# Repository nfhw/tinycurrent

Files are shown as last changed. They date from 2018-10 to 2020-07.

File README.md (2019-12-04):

# tinyCurrent – an enhanced uCurrent Gold Derivative

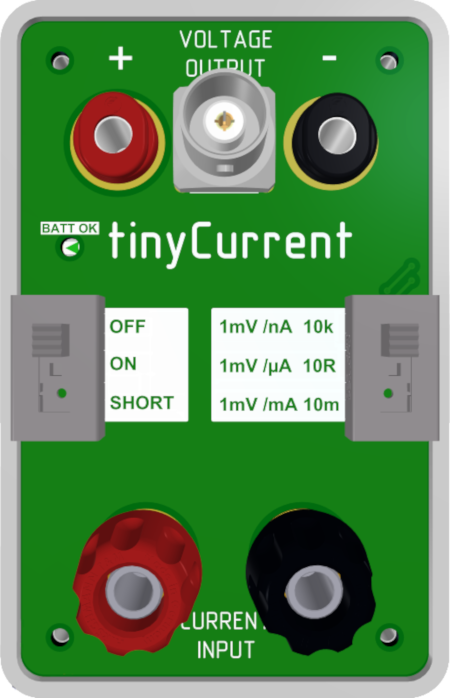
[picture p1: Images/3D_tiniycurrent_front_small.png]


A low cost yet professional low current measurement shunt and amplifier
combination to overcome the issue of high burden voltage as seen with
multimeters and to enable low current measurement by using voltage measurement
devices such as oscilloscopes.

Originally designed and sold by
[Dave Jones on the EEVBLOG](https://www.eevblog.com/projects/ucurrent/),
this derivative has several enhancements specifically for measuring varying
currents on today's low power devices.
Switch mode voltage regulators and the varying current draw of MCUs and RF
chips require the determination of the current draw over time to calculate the
total power consumption of a device. A storage oscilloscope is a perfect tool
for this task and widely available.
That's why the tinyCurrent features a **BNC connector to reduce the picked-up
noise** while measuring with an and oscilloscope. Another problem is the high
dynamics in power draw caused by the aforementioned reasons.
This is addressed by the possibility to
**power the device from an external source**
with up to 5.5 V and bridge R7 using J6 to use the whole positive VDD
as maximum positive output voltage. Both measures combined lead to
**almost 3 times higher dynamic range**.

## Modifications to the original Design

### Highlights

- Added BNC output for lower noise when acquiring data with a high input impedance instruments like an oscilloscope. The effect is lower noise compared to normal banana leads.
See all <a href="scope_shots.md">scope shots</a> for comparison.
- Added a 2-pin 1.25 mm JST ZH style male header for powering the device externally to better use the device in permanent measurement setups. **Only use without battery**.
- Allow device to be fed with supply voltage of up to 5.5 V to increase the dynamic range (only when external power source us used).
- Added header J6 which allows to install a THT resistor or bond wire to change the ratio of the voltage divider R6/ R7 to increase the dynamic range for positive currents. R6/ R7 have a ratio of 1/ 5 to allow for a max. positive output voltage of ~80% of the supply voltage.
- "R-Variant" with reversed BNC connector optimized for attaching the device directly to an oscilloscope's input via a [BNC-to-BNC adapter](https://www.telegaertner.com/en/info/catalogue/coax/?IdTreeGroup=12267&IdProduct=12538).

### Other Differences

- Increased width of some traces
- Case and board shape to fit case
- Removed test traces on PCB on all 4 corners as they are antennas
- Slide switches with lower current rating than in original design → Tests have shown that the used switch can easily handle 5V/ 6A which should be far enough for this device
- Shunt resistor R9 has 0.05% greater tolerance → Parts are hand selected using 7 1/2 Digit DMM with 4 wire measurement in 100 Ohm range
- Pads for C5, C6 to fit caps on the virtual ground rails to prevent oscillation with capacitive loads
- Some other BoM changes without negative implications

## Specifications

<table class="vclTable">
  <tr>
    <th colspan="3" style="text-align: left;">
      Min/Max Current per Range
    </th>
  </tr>
  <tr>
    <td>
      Dynamic Range
    </td>
    <td colspan="2">
      In general, the dynamic range in one direction can be determined by:<br><code>VDD / 2 - 200 mV (security margin) = X mV</code>. In case of <code>VGND = VDD / 2</code>.
    </td>
  </tr>
  <tr>
    <td colspan="3">
      @2.9V VDD (mean battery voltage over usage time)
    </td>
  </tr>
  <tr>
    <td>
      nA
    </td>
    <td colspan="2">
      ± 1250 nA (20 µV / nA burden voltage typical), contact resistance plays a role here. 10 µV due to the shunt resistor.
    </td>
  </tr>
  <tr>
    <td>
      µA
    </td>
    <td colspan="2">
      ± 1250 µA (10 µV / µA burden voltage)
    </td>
  </tr>
  <tr>
    <td>
      mA
    </td>
    <td colspan="2">
      ± 1250 mA (10 µV / mA burden voltage)
    </td>
  </tr>
  <tr>
    <td colspan="4">
      @5.5V VDD (from external power source)
    </td>
  </tr>
  <tr>
    <td>
      nA
    </td>
    <td colspan="2">
      ± 2550 nA (20 µV / nA burden voltage typical), contact resistance plays a role here. 10 µV due to the shunt resistor.
    </td>
  </tr>
  <tr>
    <td>
      µA
    </td>
    <td colspan="2">
      ± 2550 µA (10 µV / µA burden voltage)
    </td>
  </tr>
  <tr>
    <td>
      mA
    </td>
    <td colspan="2">
      ± 2550 mA (10 µV / mA burden voltage)
    </td>
  </tr>
  <tr>
    <th style="text-align: left;">
      Resolution in nA Range
    </th>
    <td colspan="3">
      1000 pA on a 3.5 digit DMM<br>
      100 pA on 4.5 digit DMM<br>
      10 pA 5.5 digit DMM
    </td>
  </tr>
  <tr>
    <th style="text-align: left;">
      Accuracy, typical
    </th>
    <td colspan="3">
      &lt; ±0.05% on µA and nA ranges<br>
      &lt; ±0.1% on mA range
    </td>
  </tr>
  <tr>
    <th style="text-align: left;">
      Output Offset Voltage, maximum
    </th>
    <td colspan="3">
      &lt; ±30 µV
    </td>
  </tr>
  <tr>
    <th style="text-align: left;">
      Temperature Drift
    </th>
    <td colspan="3">
      &lt; 10 ppm / degC (µA / nA)<br>
      &lt; 15 ppm / degC (mA)
    </td>
  </tr>
  <tr>
    <th style="text-align: left;">
      Noise
    </th>
    <td colspan="3">
      &lt; -90 dBV
    </td>
  </tr>
  <tr>
    <th style="text-align: left;">
      THD
    </th>
    <td colspan="3">
      &lt; -60 dB
    </td>
  </tr>
  <tr>
    <th style="text-align: left;">
      Bandwidth (-3 dB)
    </th>
    <td colspan="3">
      300 kHz
    </td>
  </tr>
  <tr>
    <th style="text-align: left;">
      Power Supply
    </th>
    <td colspan="3">
      CR2032 Lithium coin cell <b>or</b> max 5.5 V through connector J5
    </td>
  </tr>
  <tr>
    <th style="text-align: left;">
      Battery Life
    </th>
    <td colspan="3">
      &gt;50 hours (battery good LED ensures accurate measurement when LED is on). 2.65 V cutout voltage.
    </td>
  </tr>
  <tr>
    <th style="text-align: left;">
      Certifications
    </th>
    <td colspan="3">
      CE
    </td>
  </tr>
  <tr>
    <th style="text-align: left;">
      Materials
    </th>
    <td colspan="3">
      RoHS, REACH
    </td>
  </tr>
</table>

Similar to the [original uCurrent Gold specs](https://www.eevblog.com/projects/ucurrent/).

## Maximum Ratings

- Maximum supply voltage: 5.5 V
- Maximum current through input ports: 5 A

In order to keep the burden voltage low, this device has no
**OVERLOAD PROTECTION**. That means **NO FUSES**. Care is required in
using the unit to prevent damage.

## Schematics and PCB Design

All source files are [available on Github](https://github.com/nfhw/tinycurrent).
The schematics and PCB layout are in Altium Designer format.

## Kit Contents

- tinyCurrent PCB and case plus 4 screws
- **no** battery, you need a CR2032 coin cell battery

## Usage

1. If you supply power via J5, make sure the noise level is lower than the expected output voltage.
**Too much noise on the supply voltage will render any measurement useless. Usually primary cells (batteries) are the best choice for this**.
2. Connect the device under test in loop **on the low side** so that the current flow is from **+** to **-**.
3. Connect a suitable voltage measurement device such as a DMM or an Oscilloscope on the output side.
4. Turn on the device and read the current on the voltage measurement device in the mV range as if it were mA/µA/nA.

## Where to buy?

Pick it up ready to use from the [n-fuse website](https://www.n-fuse.co/devices/tinyCurrent-precision-low-Current-Measurement-Shunt-and-Amplifier-Device.html).

## Licenses

### Circuit Schematics

The circuit schematics of this project are made available under the
[CC-BY-SA](https://creativecommons.org/licenses/by-sa/3.0/) license.

### Hardware Design

 Open source hardware.

### Miscellenious

Data sheets, Altium libraries, 3D Models are subject to vendor specific
licensing.

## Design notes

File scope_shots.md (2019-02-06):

# Scope Shots to highlight the Benefits of the tinyCrrent's Design

## Coax Cable vs. Banana Leads

This comparison shows the effect of using a Coax cable (using the BNC output connector)
to connect the tinyCurrent to a scope compared to normal banana plug leads of approximately the same length
(15 cm).
Both cable types are wired to an input channel configured in 1:1 mode.

**Input Short, Output connected to Scope with Banana Leads**

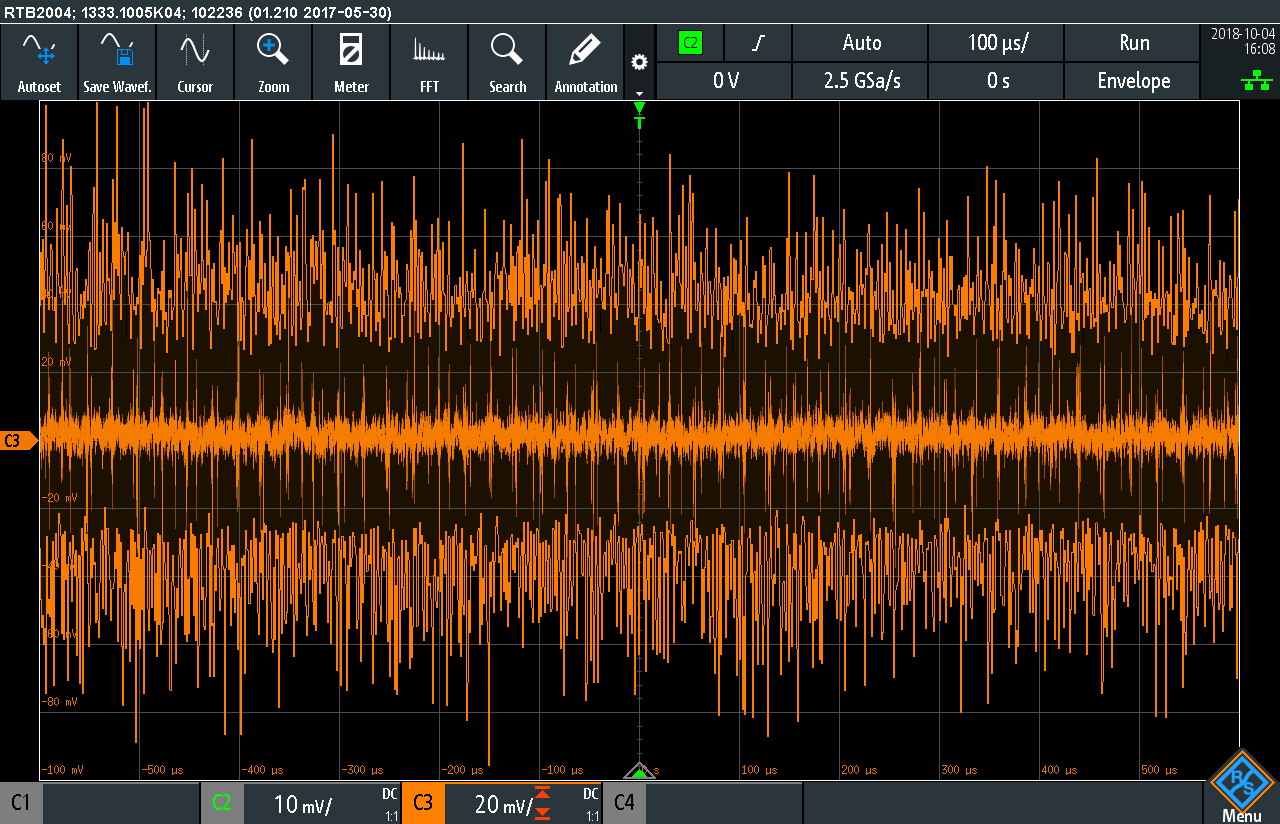
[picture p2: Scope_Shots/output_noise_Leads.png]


**Input Short, Output connected to Scope with Coax Cable**

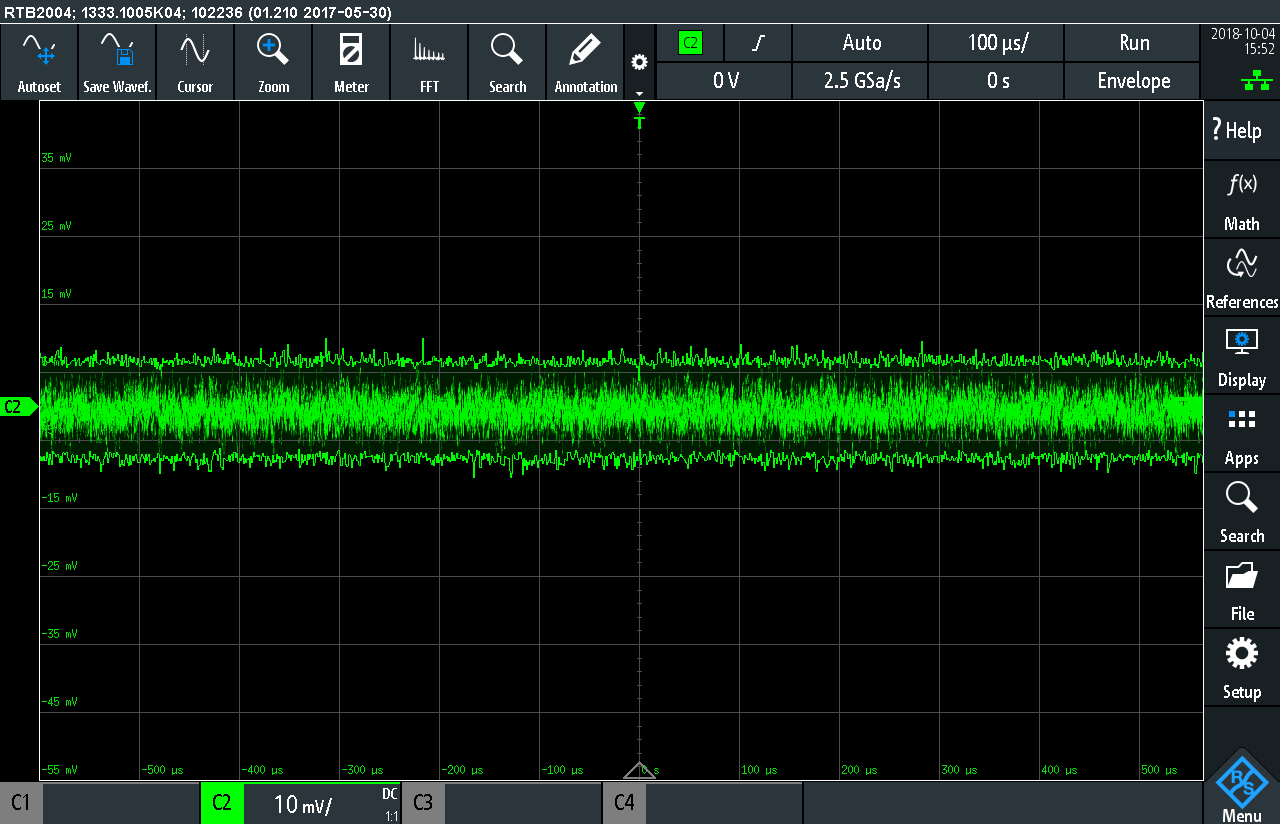
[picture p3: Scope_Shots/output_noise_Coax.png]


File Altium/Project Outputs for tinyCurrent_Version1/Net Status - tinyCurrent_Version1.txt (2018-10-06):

Net Status Report
Filename     : \\VBOXSVR\Xingular\tinycurrent\tinyCurrent_Version1.PcbDoc
Date         : 11/1/2017
Time         : 10:53:23 PM
Time Elapsed : 00:00:00

Nets, Layer, Length
    +IN, Signal Layers Only, 115.4395mm
    +V, Signal Layers Only, 138.4734mm
    -IN, Signal Layers Only, 81.1459mm
    -V, Signal Layers Only, 138.0222mm
    B+, Signal Layers Only, 58.0367mm
    NetBC1_1, Signal Layers Only, 54.8503mm
    NetC3_1, Signal Layers Only, 8.2573mm
    NetC3_2, Signal Layers Only, 17.4929mm
    NetC4_1, Signal Layers Only, 6.1419mm
    NetD1_2, Signal Layers Only, 3.1914mm
    NetR10_2, Signal Layers Only, 5.9889mm
    NetR12_1, Signal Layers Only, 18.3543mm
    NetR12_2, Signal Layers Only, 2.1717mm
    NetR13_2, Signal Layers Only, 2mm
    NetR1_1, Signal Layers Only, 9.5646mm
    NetR1_3, Signal Layers Only, 2.35mm
    NetR3_2, Signal Layers Only, 2.1mm
    NetR4_2, Signal Layers Only, 5.0923mm
    NetR6_1, Signal Layers Only, 21.6636mm
    NetR8_2, Signal Layers Only, 2.2mm
    NetR9_1, Signal Layers Only, 15.8148mm
    VGND, Signal Layers Only, 102.462mm
count : 22

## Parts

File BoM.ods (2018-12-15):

Reference | Quantity | Description | Manufacturer | Manufacturer Part Number |  | Alt. Replacement
U1, U4 | 2 | IC OPAMP Precision Amplifiers Low Offset/Drift | Maxim Integrated | MAX4239AUT+T
U2 | 1 | IC OPAMP GP 1.3MHZ RRO SOT23-5 | ST Microelectronics | LMV321ILT
U3 | 1 | IC MPU RESET CIRC 2.63V SOT23, Active Low | ST Microelectronics | STM809RWX6F
R1 | 1 | Resistor 0.01ohm 0.1% 15ppm 2512 package | Vishay | Y14870R01000B9R
R5, R15 | 2 | 1K 0.05% 0603 10ppm | Susumu | RG1608N-102-W-T1
R3, R13 | 2 | 6K8 0.05% 0603 10ppm | Susumu | RG1608N-682-W-T1
R11, R14 | 2 | 2K2 0.05% 0603 10ppm | Susumu | RG1608N-222-W-T1
R2 | 1 | 10K 0.05% 0603 10ppm | Susumu | RG1608N-103-W-T1
R9 | 1 | 10R 0.05% 0805 10ppm | Stackpole | RNCF0805AKT10R0 | Replacement: RP73D2A10RBTG
R6 | 1 | 100K 1% 0603 | KOA | RK73H1JTTD1003F
R7 | 1 | 100K 1% 0603 | KOA | RK73H1JTTD1003F
R4 | 1 | 470R 1% 0603 | KOA | RK73H1JTTD4700F
R8, R10, R12 | 3 | 270R 1% 0603 | KOA | RK73H1JTTD2700F
C1, C2 | 2 | 100nF 16V 0603 X7R Capacitor | Würth Electronik | 885012206046
C3, C4 | 2 | 10pF 50V 0603 NP0 capacitor | Würth Electronik | 885012006051
SW1, SW2 | 2 | Slide switch | Knitter-Switch | MFP 230
BT1 | 1 | Battery holder | Würth Electronik | 79527141
D1 | 1 | 1206 LED Green, reverse mountable | Würth Electronik | 156120GS75000
BC1 | 1 | BNC Connector | Telegärtner | J01001A1944
J1 | 1 | Binding post/Pole clamp PK 10 A RED | SKS Kontakttechnik | 930099101
J2 | 1 | Binding post/Pole clamp PK 10 A BLACK | SKS Kontakttechnik | 930099100
J3 | 1 | Binding post/Pole clamp BUG 10 RED | SKS Kontakttechnik | 930175101
J4 | 1 | Binding post/Pole clamp BUG 10 BLACK | SKS Kontakttechnik | 930175100
J5 | 1 | 1.25mm SMT Male Horizontal Shrouded Header (JST) | Würth Electronik | 653102131822
J6 | 1 | SMT Socket Header, pitch 2.54mm, 4p | Würth Electronik | 61000413321
 | 1 | Pocket Size Enclosure | Altinkaya | HH-012 Light Gray
 | 4 | Screws |  | 4232/1151522009
 | 1 | PCB | IBR Leiterplatten
 | 1 | Packaging
Acessories / Optional/ Non-fitted Parts
 | 1 | Coin Cell Battery | Varta | CR2032
 | 1 | 1.25mm JST 2-Pin Male Connector Wire | Aliexpress
 | 1 | BNC-Adaptor 50R male / male | Telegärtner | J01004A0806
C5, C6 | 2 | 100nF 16V 0603 X7R Capacitor | Würth Electronik | 885012206046

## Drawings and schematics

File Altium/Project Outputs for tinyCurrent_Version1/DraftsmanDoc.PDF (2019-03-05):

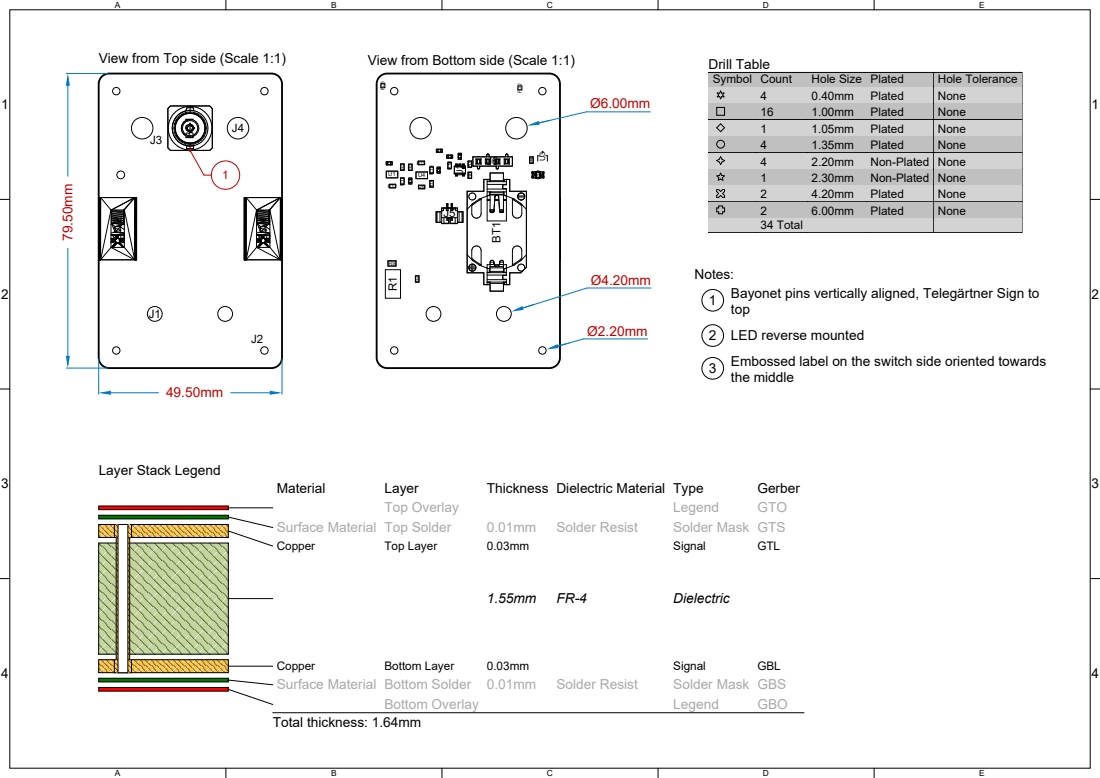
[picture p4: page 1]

View from Top side (Scale 1:1)

View from Bottom side (Scale 1:1)

Symbol | Count | Hole Size | Plated | Hole Tolerance

4 | 0.40mm | Plated | None
16 | 1.00mm | Plated | None
1 | 1.05mm | Plated | None
4 | 1.35mm | Plated | None

2 | 4.20mm | Plated | None
2 | 6.00mm | Plated | None
34 Total

Notes:
Bayonet pins vertically aligned, Telegärtner Sign to
top
2 LED reverse mounted
Embossed label on the switch side oriented towards
the middle

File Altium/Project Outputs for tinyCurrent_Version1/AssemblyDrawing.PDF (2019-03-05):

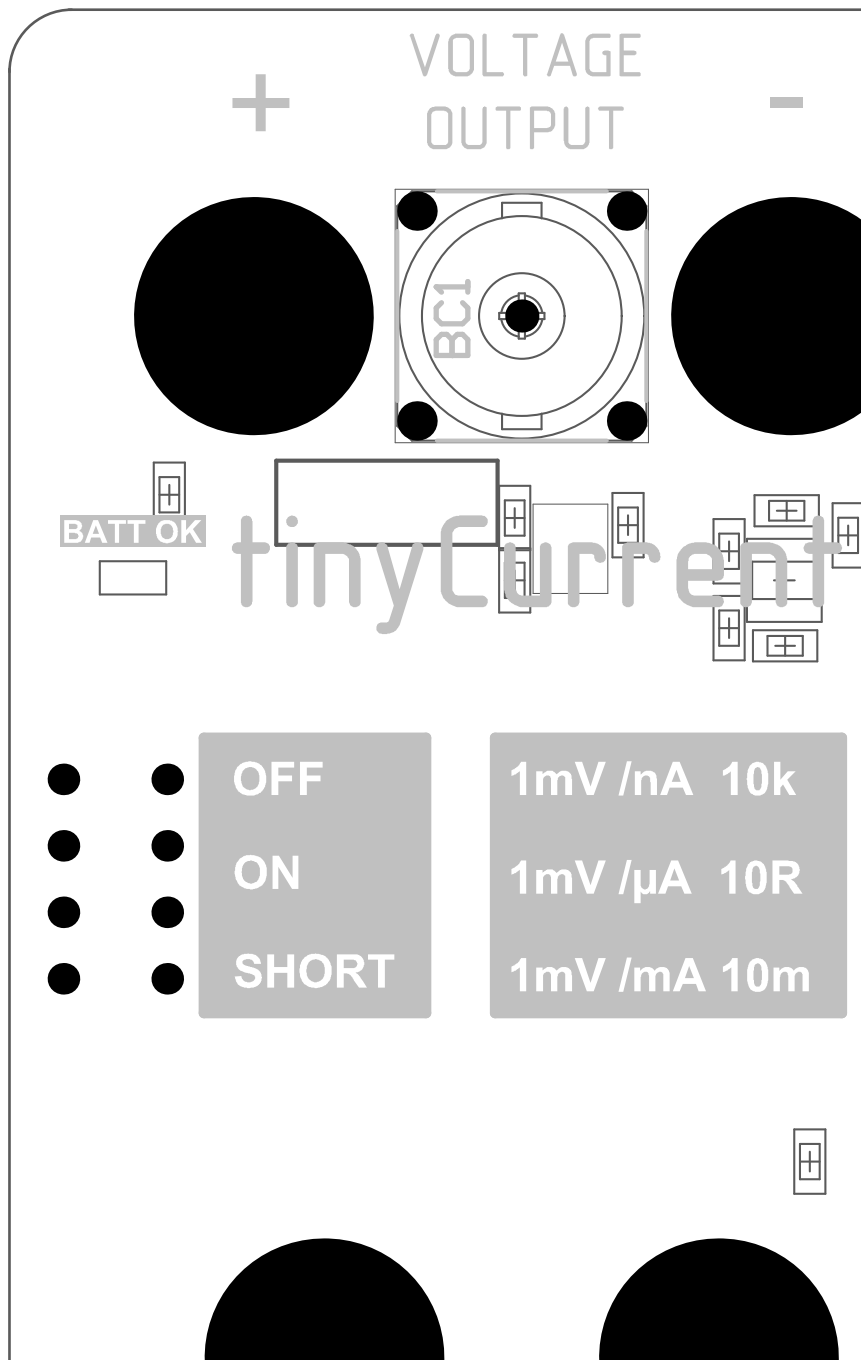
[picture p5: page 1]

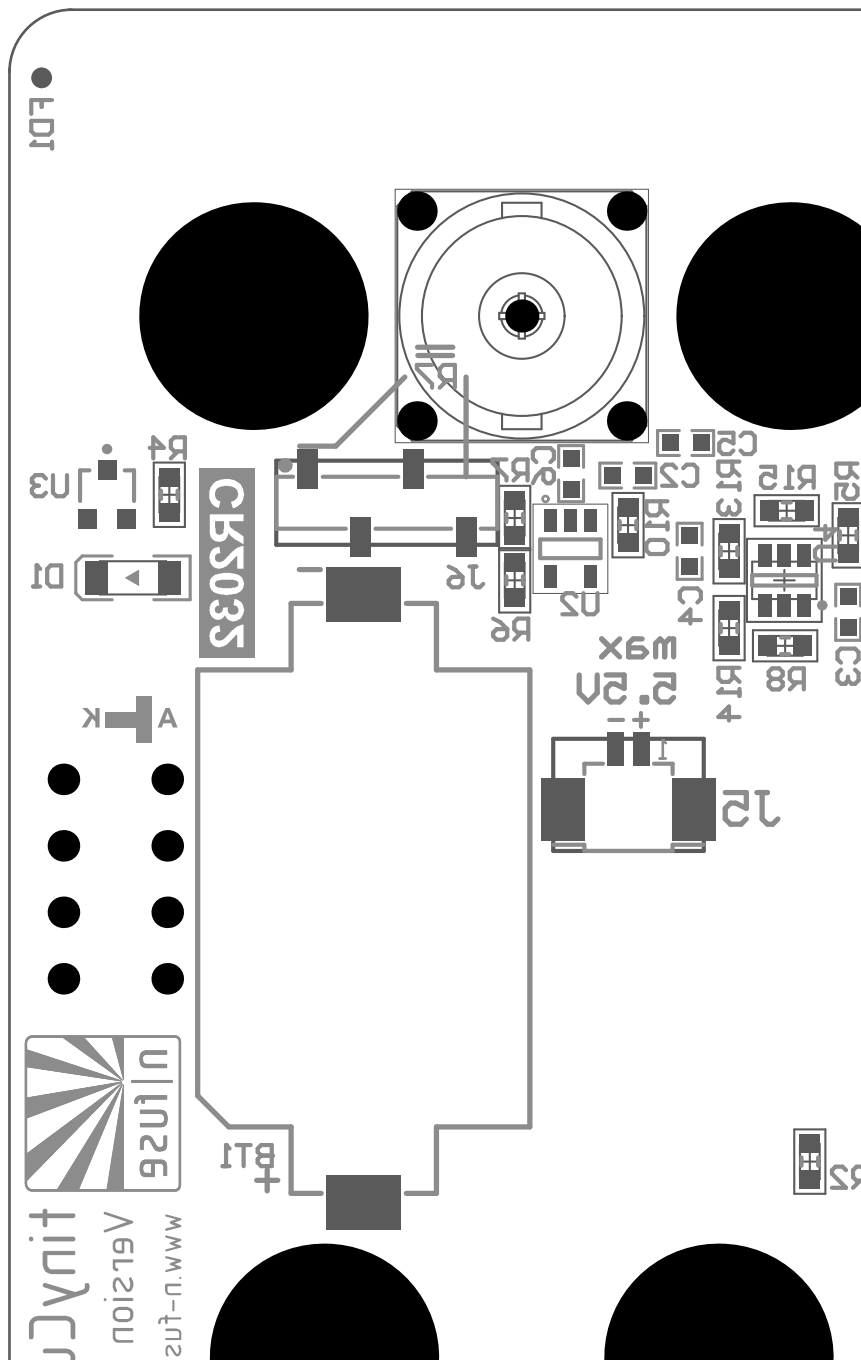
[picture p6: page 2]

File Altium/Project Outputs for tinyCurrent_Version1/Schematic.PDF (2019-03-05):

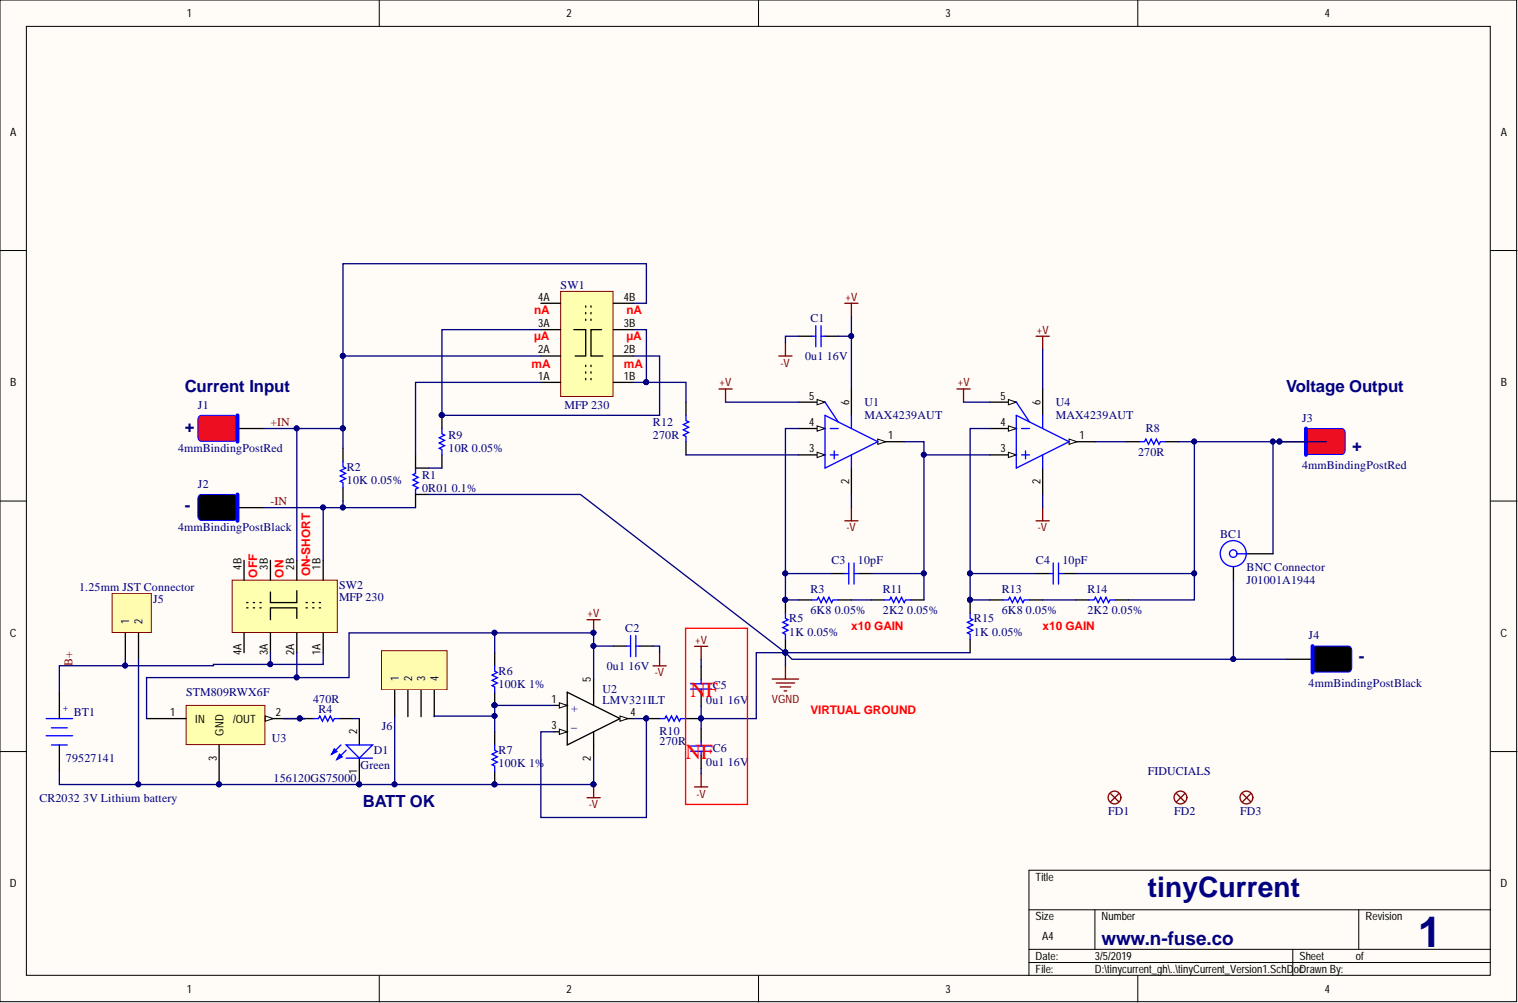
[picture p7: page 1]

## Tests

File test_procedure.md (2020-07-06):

# tinyCurrent Test Procedure

## Resistive Load

* Multimeter connected to the Device under Test (DUT) output using **short leads**.
* 5 VCC Load power supply.
* Device turned ON.
* Test the following current ranges and respective loads:

|Current Range  |Load (precise value) [Ohms]	|Expected Output [mV]	|Min [mV]		|Max [mV]		|Accuracy	|
|--:		|--:				|--:			|--:			|--:			|--:		|
|1mV/nA 	|50M (52.7)			|95	 		|90.2			|99.7			|0.05%		|
|1mV/uA 	|47K (46.80) 			|106.83 		|101.4			|112.2			|0.05%		|
|1mV/mA 	|47R (47.20)	 		|105.93			|95.3			|116.56			|0.1%		|

**Important Node**: The device can output a symmetric negative and positive output voltage to cover negative and positive currents so in theory it does not make a difference how the device is wired up. We have found, however, that in the nA range it is more likely to experience oscillation when the negative input is connected to positive side of the source or in other words if the device is used in reverse direction.

## Offset Voltage

* Power switch to the SHORT position.
* The current range doesn't matter as it is shorted.
* Measure the output voltage with a multimeter (DMM7510) and avoid touching the setup.

| Expected Outout Value	|
|--:			|
| < 30 µV		|

In comparision some uCurrent Gold with TI opamp can haveup to 200 µV as can be seen [here](https://youtu.be/1VlKoR0ldIE?t=1709).

## Offset Voltage with a capacitive Load

Capacitive loads on the output terminals might cause instability in the virtual ground OpAmp and deteriorate the offset voltage performance. The DUT has to be tested the following loads and its expected to not show any changes on its typical offset voltage.

| Capacitive Loads	| 
|--:			|
| 680pF			|
| 2.04nF (3x680pF)	|
| 3.4nf (5x680pF)	|
| 100nF			|
| 10uF			|
| 100uF			|

## AC Performance and Noise

### Bandwidth

The bandwidth can be measured by finding the -3dB cutoff frequency. The tinyCurrent has a low-pass filter response typical from OpAmps, so the -3dB cutoff frequency is where the amplitude of the output signal is 0.707 of the DC output voltage. Assuming that the amplitude at 8 Hz is approximately the same at 0 Hz, the cuttoff frequency can be found using the VSG and the DSO using the following procedure:

* Using a sine-sweep wave of -15dBm from 8 KHz to 800KHz. Set the Linear steps and the Dwell Time, so the signal goes slow enough for you to find the cuttoff frequency on the screen, The recommendation is 500 Hzfor the Linear steps and 10 ms for Dwell Time. 
* a 47 Ohms load and 1mV/uA (10 Ohms) current range. Remember that it must be in series configuration with the tinyCurrent! 
* Measure the output Vpp or amplitude at 8KHz. Use this value to find the amplitude at the cutoff frequency (0.707\*Amplitude) and set the horizontal cursors. Another way is just use the Vpp measurementi functionality.
* Now start the frequency sweep in the VSO and stop it when you find the cutoff frequency,
* For better precision, the frequency sweep can be done manually. 

### THD

THD can be measured by measuring the harmonic components of the original signal. These amplitudes can be measured by applying a FFT to the output signal.
Bear in mind that THD varies with frequency and amplitude. The recomendation is to use a fixed amplitude in the working range (2 Vpp in the output), and measure at some interesting points inside the bandwidth. For example: of 8kHz, 80kHz, and 160kHz.
The method to measure THD in a particular frequency is described in the following steps:

Using a fixed amplitude sine wave, and measuring the FFT at 8 Khz, 80 Khz, 160 Khz, 300 Khz , 450 Khz, 1MHz
* Vector signal generator sine output at -12 dBm, the important thing here is to not saturate the opamps. 
* 46R resistor in series with the tinyCurrent input, current range to 1mV/1uA; 
* DSO in high resolution signal acquisition, FFT using a Blackman window and average mode. 
* For each frequency of interest, the fundamental and its harmonics amplitudes have be written on a table like the following:

| Freq (kHz)	| Harmonic #	| Pout (dBm)	| Vout (V)	|
|--:		|--:		|--:		|--:		|
|		|1		|		|		|
|		|2		|		|		|
|		|3		|		|		|
|		|4		|		|		|
|		|5		|		|		|	
|		|6		|		|		|
|		|7		|		|		|

* Vout is calculated from the dBm values. After the conversion, the THD is ready to be calculated by the formula:

THD_f

Reference: 
* Method 2 at [microsemi AN30](https://www.microsemi.com/document-portal/doc_view/134813-an30-basic-total-harmonic-distortion-thd-measurement)
* Available in [wikipedia](https://en.wikipedia.org/wiki/Total_harmonic_distortion).  

### Noise Floor

Procedure:

* FFT rectangular window and measurements in dBV.
* The noise floor is measured after the 1/f noise frequency range.
* This measurement is subjected to the DSO noise, so first we measure with the tinyCurrent turned off, and then in the SHORT position.

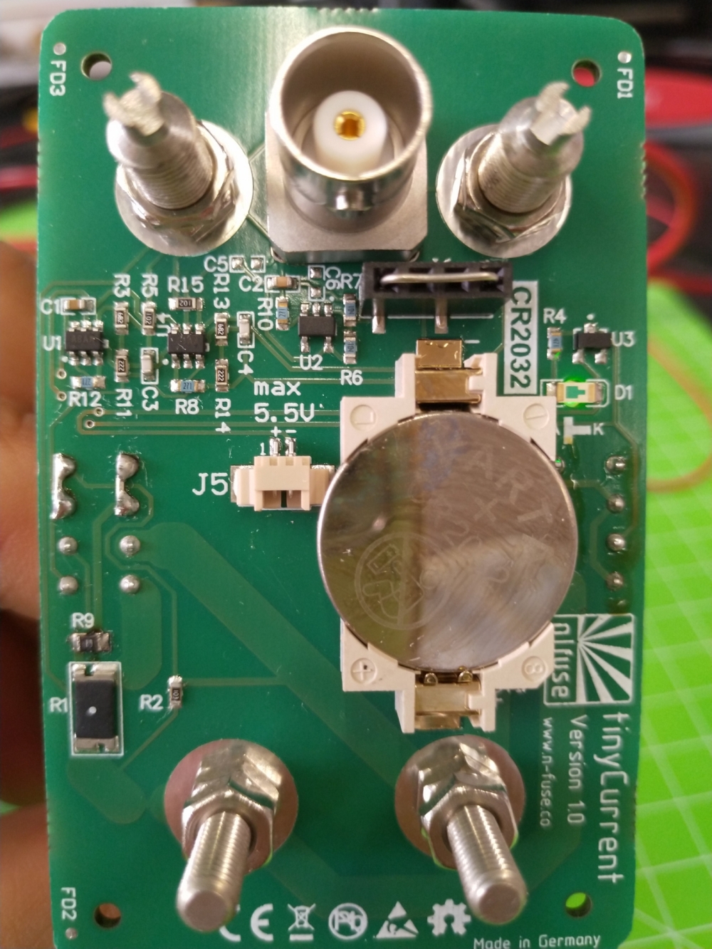
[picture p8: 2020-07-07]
Scope_Shots/contact_resistance_test_mod.jpg

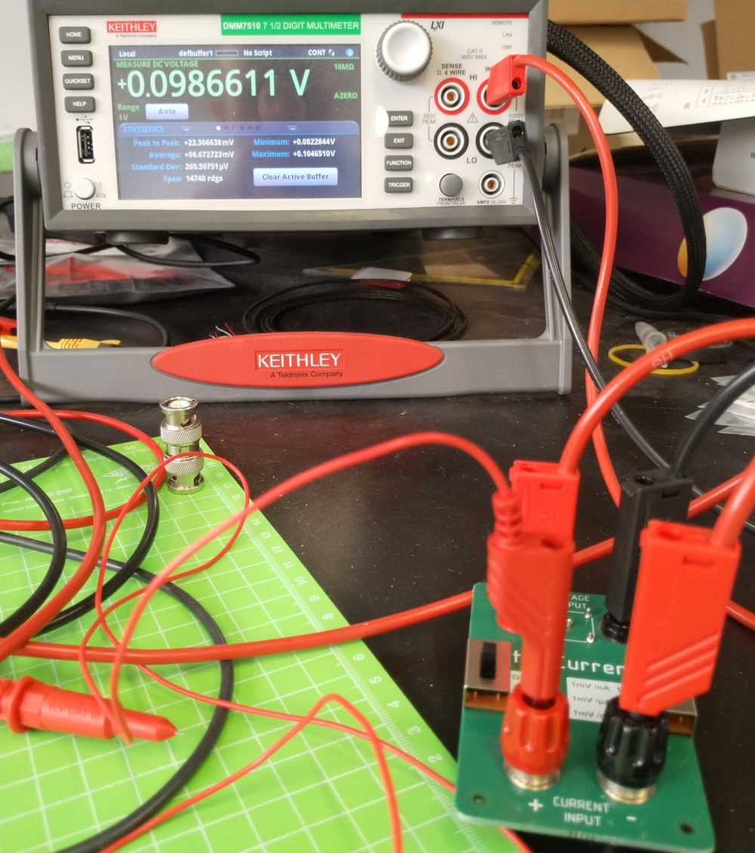
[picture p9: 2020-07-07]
Scope_Shots/contact_resistance_test_after.jpg

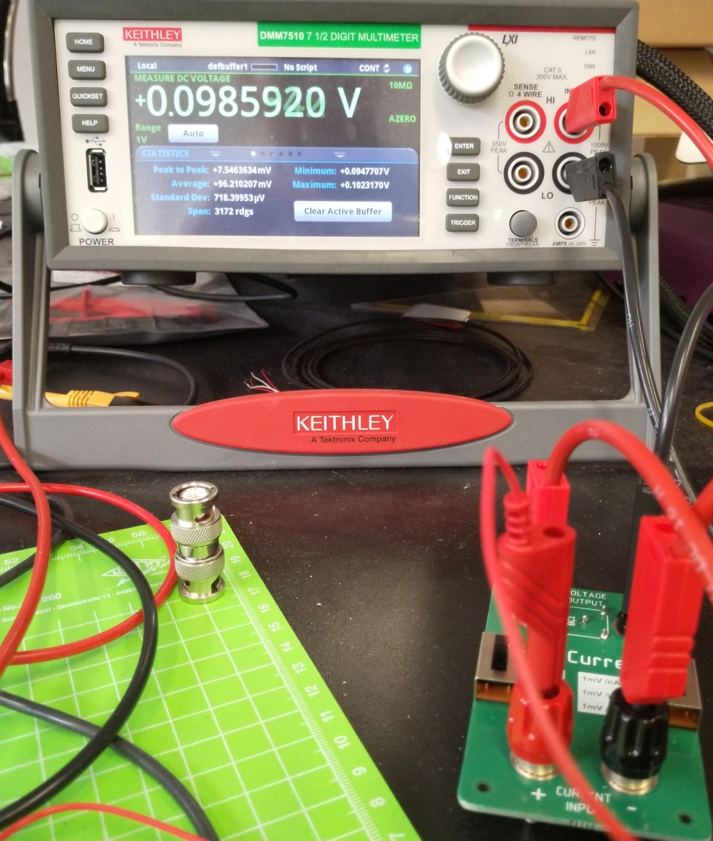
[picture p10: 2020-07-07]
Scope_Shots/contact_resistance_test_before.jpg

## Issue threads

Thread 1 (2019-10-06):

Add screwless terminal block for input terminals (feature request)

hattesen, 2019-10-06:
For a future revision, It would be really convenient to have the input terminals (current) available on a screwless terminal block, to avoid the requirement for bulky banana-plug test cables, when testing breadboard (and similar) circuits.

Something with a pitch of at least 5 mm would be ideal.

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

vanthome, 2019-10-10:
In fact a valid point. We will consider it.

vanthome, 2019-11-22:
@hattesen I have responded to your email ages ago. Did you not receive it? Is it maybe in spam?

vanthome, 2019-11-22:
@hattesen I have responded to your email ages ago. Did you not receive it? Is it maybe in spam?

hattesen, 2019-11-22:
Not received any reply on mail from 25 October.
/Morten

fre. 22. nov. 2019 18.21 skrev Thomas Hoppe <notifications@github.com>:

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

vanthome, 2019-11-23:
I have sent it again to your medicool address, can you please check?

hattesen, 2019-11-23:
Nothing. Never happened before. Pls try morten.hattesen@gmail.com

/Morten

lør. 23. nov. 2019 21.57 skrev Thomas Hoppe <notifications@github.com>:

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

vanthome, 2019-11-30:
unbelievable, what provider is behind this? I have sent it now to the gmail address.

vanthome, 2020-07-07:
@hattesen have you seen my mail?

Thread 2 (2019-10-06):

Schematics in PDF format

hattesen, 2019-10-06:
For those of us, who do not have Altium designer installed, it would be really useful to have the TinyCurrent circuit schematics available in PDF format files.

vanthome, 2019-10-06:
Oh, they are, just look here: https://github.com/nfhw/tinycurrent/blob/master/Altium/Project%20Outputs%20for%20tinyCurrent_Version1/Schematic.PDF

Closed 2019-10-06.

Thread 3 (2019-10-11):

DC accuracy in mA range

patzf, 2019-10-11:
Maybe I am overlooking something here, but you use a 10mOhm resistor as shunt for the mA range. The slide switch has (according to the datasheet) <20m Ohms.
You specify an accuracy of 0.1% in the mA range. How should that work if the "reference" resistor is in series with the switch? Even for 10m Ohms for the switch, the error is huge?

vanthome, 2020-07-07:
Hi, sorry for my late reply. This is a very good question and yes, the "accuracy" as stated on the product page is 1:1 the tolerance of the corresponding shunt resistors. And then -- at least in the mA range -- it cannot be correct considering the contact resistance of the switch as per data sheet.
**But** I just did a reference measurement measurement for the nA range as described here:
https://github.com/nfhw/tinycurrent/blob/master/test_procedure.md

- I measured with only the slide switch in nA range
- I have bridged the connections that are connected through by the slide switch with a solder bridge

I took 3 pictures correspondingly and checked them in here:
https://github.com/nfhw/tinycurrent/tree/master/Scope_Shots

As you can see there is virtually no difference, the variance of the measurement over time is much bigger than the difference.
That means that the contact resistance has only a negligible impact probably because it's smaller than given in the data sheet.

Also the reference measurement described here
https://github.com/nfhw/tinycurrent/blob/master/test_procedure.md
Could not be so good, if the contact resistance would be as given in the data sheet.

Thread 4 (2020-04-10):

Stability issue

jricaee, 2020-04-10:
There might be a stability issue when introducing capacitive loads. This is seen on one of Dave's EEVBlog videos about the uCurrent (https://www.youtube.com/watch?v=1VlKoR0ldIE).
The issue seems to be a design mistake. Which is the output 270 Ohm resistor being INSIDE the feedback loop of the last amplifier. When capacitance is introduced on the output, it will create a big phase shift (depending on the capacitance value) and can make the amplifier oscillate.
The solution is to simply remove the 270 Ohm from inside the loop and place it directly on the output before the binding post.
For people that already have Dave's uCurrent or the tinyCurrent version, the easiest fix is to remove the 270 Ohm resistor, bridge the pads, make a small cut on the output track going to the binding post and solder the 270 Ohm there.

vanthome, 2020-04-18:
Hello,
yes, we are aware of the stability issues and that's why we have unpopulated capacitors that for the caps that Dave recommends in this video:

https://www.youtube.com/watch?v=l2LBkXxN81Y

We found that the issue only happens in very rare cases and these caps reduce the BW so we don't fit them by default.

Regarding the 270 Ohm resistor in the feedback loop: Have you actually tried what you claim here?
I think this resistor is especially required to dampen the bias to oscillate. I even think we have tried to remove it and it was by no means better but I'm not 100% sure.

BG, Thomas

jricaee, 2020-04-18:
Hello,
I'm glad for your reply.
Yes I would not populate those caps on the output of the virtual ground
opamp, but rather on its input, in parallel with the 100k resistor divider,
to have more "stable" reference voltage for the virtual ground (acts like a
LPF, less susceptible to interference).
About the 270 Ohm resistor on the output amplifier:
It's ok to have it on the output of the amplifier for that very reason, to
avoid oscillation of the amplifier when adding capacitance. But for sure it
should be outside the feedback loop, otherwise any capacitance on the
output would make a phase shift on the loop and could make it oscillate.
(Attached is the original Dave schematic with my added notes)
I did not yet tried this, I'm currently waiting for the PCBs. I will inform
you of the results if you would like.
[image: uCurrent.png]

I've put together a simulation of the amplification circuit with the 270
Ohm resistor inside and outside the feedback loop. It clearly shows that
with the resistor outside the loop we have a nice dampened frequency
response, as opposed to having it inside the loop where we a an oscillation
at some frequency (dependent on the output capacitance).

[image: image.png][image: image.png]

Best regards,
Joao Graca.

On Sat, Apr 18, 2020 at 10:40 PM Thomas Hoppe <notifications@github.com>
wrote:

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

vanthome, 2020-04-20:
hmm interesting, according to this:
https://www.analog.com/media/en/analog-dialogue/volume-38/number-2/articles/techniques-to-avoid-instability-capacitive-loading.pdf

both is possible (to have the R in and out-of the loop). The variant out-of the loop however has the clear disadvantage that it has an impact on the DC accuracy (it causes an offset) which is a no-go for this find of device. Secondly according to the simulation, the attenuation at only 1 kHz is already  -40 dBm which is also quite tremendous, especially for the use cases I have.

Also as mentioned in the document, the value of the resistor is heavily dependent on the actual amplifier and I don't know how good the spice models of the MAX4239 actually is that you are using.

jricaee, 2020-04-22:
I think Dave meant for the uCurrent to be used with multimeters having
10MOhm of input impedance ( https://www.youtube.com/watch?v=g7b5YZENvjY),
that is why the resistor has a low value of 270 Ohm, giving a DC error of
27ppm. (Also in that video he had the resistor outside the loop)
As described in the document, it is possible to have the resistor in the
loop for reduced error. But then the loop capacitor still needs to
connect before the resistor to avoid oscillation, and the optimum value for
this capacitor value depends on the output capacitance placed on the
terminals (Which is unknown).
On my simulation the attenuation is -40dBm at 1kHz because I've used a
fairly big capacitor of 100uF on the output, with less capacitance there
will be less attenuation (RC filter with the 270Ohm).

BR

On Mon, Apr 20, 2020 at 11:22 AM Thomas Hoppe <notifications@github.com>
wrote:

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

GP108, 2020-05-05:
Hi there in the original UCurent    R9 is outside the feedback loop..  then in the latter revision R8 is inside the feedback loop...  clearly looks like an error   GP

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

GP108, 2020-05-05:
I re checked and they are defiantly different the original and the latest revision with regard to the O/P series resistor, First version outside the feedback path, latest version inside the feedback path...

vanthome, 2020-05-07:
We used the latest version when we derived the tinyCurrent, that's why it's inside the loop. But where do you see the "clear error"?

GP108, 2020-05-08:
Hi there  Thomas     I hope you are well..

The only difference I see, is that the first version has the series resistor outside the feedback loop and then the latest version has the series resistor inside the feedback loop..

Why there was a change of circuit design I do not know…

Also if you look up    currentranger   which is a similar design to EEVBLOG, they added a low pass filter which is a nice Idea perhaps it might be worth adding  to your version as well..

Wishing you well

Graham…

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

pascaldornfeld, 2021-05-24:
I just built the original uCurrent. I used an opa335 instead of the max4239 because it was a recommended alternative in a forum (sure its worse) and the max was not available.

When shorting the inputs I can usually voltages up to 3v with my multimeter in dc mode but when going to ac mode it goes down to 0.1v. I guess it is oscilating but I dont have a scope to verify. First of all, just putting a 10pF cap between v- and vgnd did not change anything. I will get a scope soon to actually check what is going on.

I want to understand completely how the logic works and I am not sure about the gain logic. To get a x10 gain we need 9k ohms which we get with R3 and R11 or R13 and R14. First, why do we need C3 and C4? Is it just a "for stability"-thing (why there?) or is it doing some opamp-integrator-curcuit stuff? Next, I do not get at all, why R8 was changed to be inside the feedback curcuit. Does it not change the gain to x10.25? Does it not remove the purpose of R8 to decouple from the output because the output is now directly connected to the feedback?

nonplussed, 2021-06-09:
I believe the best option for stable capacitive loads is to keep the R8 within the feedback loop, but to change the C4 from the right side of R8 to the left side of R8 (directly to U4p1).  Or perhaps just an additional capacitor from U4p1 to U4p4. I haven't tried it yet - but to be honest, I don't think driving capacitive loads is a concern for me/my use.

On a separate note - although the noise level is pretty decent - I'm considering substituting an OPA388 although the current draw is much higher, the noise should be much lower.

vanthome, 2021-09-29:
@nonplussed let us know if swapping out the Opamp brought any improvement please.

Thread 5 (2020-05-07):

Thin track

Tomsiik, 2020-05-07:
Why is there a thin track between -IN terminal and the sense resistor?
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

vanthome, 2020-05-11:
Hi, this is a "fuse", so in case of an over current, this trace will be interrupted.

Closed 2020-05-11.

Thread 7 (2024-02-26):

J5 battery connector specification

hattesen, 2024-02-26:
The [README.md](/nfhw/tinycurrent/blob/master/README.md) document specifies the J5 battery connector as _"2-pin 1.25 mm JST ZH style male header"_.

However, the [JST ZH connector](https://www.jst.com/products/crimp-style-connectors-wire-to-board-type/zh-connector/) has a 1.5 mm pitch.

While the J5 [male PCB connector](https://www.we-online.com/components/products/datasheet/653102131822.pdf) does have a 1.25 mm pitch, the "ZH" designation is wrong.

It might be a good idea to update and possibly specify a supplier and part number for a female connector matching J5. I believe the connector is colloquially called "JST 1.25" (Chinese suppliers), although I have not been able to locate the connector in the [JST product catalog](https://www.jst-mfg.com/product/index.php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).

SubaruArai, 2024-03-28:
@hattesen A commonly misunderstood connector as JST 1.25mm is the "Molex PicoBlade" series.
Maybe this is what's used?

SubaruArai, 2024-03-28:
My bad, this was a WE 653102131822, written in the BOM.

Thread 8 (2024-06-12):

Maximum voltage on the current input

tondacrha, 2024-06-12:
Hello. After reading through the documentation, I'm a bit unclear what is the maximum rated voltage on the current input. All the components certainly have a voltage rating. The 0805 resistors typically have a 150V rating.

Can you please help me out by explaining me what is the maximum allowed voltage? Thank you

tondacrha, 2024-06-17:
After some more research, I feel like I can reply to myself.

There is no point in the device where a true earth potential is present. Mostly because it's a battery powered floating device. As far as internal components of the tinycurrent meter are concern, the only voltage on the input clamps is the shunt voltage drop itself.

That being said, it's a oversimplification. It is possible (and very likely, as a matter of fact) to introduce some amount of capacitive coupling to the groud.

So, technically (NOT a good idea, please do not attempt yourself), you can use this device to measure a mains LINE (phase in EU) currents as long as the device remains truly floating with no harm done to the sensitive amplifiers inside.

Given tinycurrent it not properly isolated for measuring mains, it's very likely you will harm yourself and the device in the process. If not by touching something that is on LINE potential while being grounded, then by introducing capacitive coupling.

For my purpose of measuring the mains PE currents on oscilloscope, this device is relatively safe to be used. I will introduce additional safety measures though.

tondacrha, 2024-06-17:
Closing

Closed 2024-06-17.

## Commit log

2018-10-06 Initial share
    [BoM.ods, tinyCurrent_Version1.PcbDoc, tinyCurrent_Version1.PrjPcb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]
2018-12-15 Correct BoM
    [BoM.ods]
2019-02-06 Version 1.1
    [BoM.ods, tinyCurrent_Version1.PcbDoc, tinyCurrent_Version1.PrjPcb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]
2019-02-13 Add silcscreen descrption for J6
    [tinyCurrent_Version1.PcbDoc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]
2019-03-05 Adapt to new casing version
    [tinyCurrent_Version1.PcbDoc, tinyCurrent_Version1.PrjPcb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]
2019-06-12 Add pnp files
    [tinyCurrent_Version1_Copper_Signal_Bot.gbr, tinyCurrent_Version1_Copper_Signal_Top.gbr, tinyCurrent_Version1_Keep-out.gbr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]
2020-07-07 Add new images for testing contact resistance
